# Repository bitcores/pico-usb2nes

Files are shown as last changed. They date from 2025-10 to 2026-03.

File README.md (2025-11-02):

# pico-usb2nes
RP2040 driven USB to controller interface for NES

This is based on the pico-usb2famikb project, using the same library for communicating with the NES/FC, but is focused on connecting to the controller port.

The only mode supported by default is the USB Keyboard Mouse Host mode (see [https://forums.nesdev.org/viewtopic.php?p=202489](https://forums.nesdev.org/viewtopic.php?p=202489) )

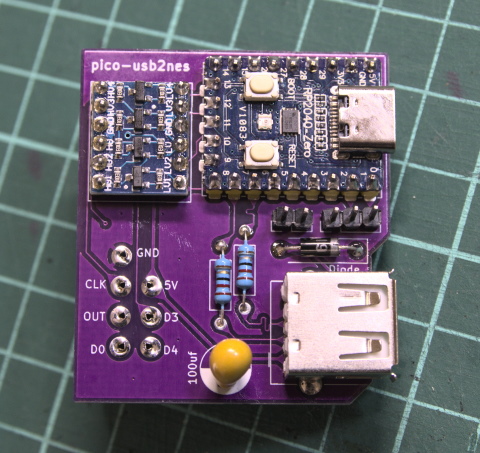
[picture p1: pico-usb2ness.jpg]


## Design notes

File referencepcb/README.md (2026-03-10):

# pico-usb2nes Reference PCB
This directory contains reference a PCB design for the pico-usb2nes. It has not been designed by a experienced engineer, but it DOES work.

If you have some experience designing circuits like this, I would very much welcome improved designs.

For the reference design you will need:
* 1x Waveshare compatible RP2040-Zero
* 1x diode (I am using a 1N5819, 1N5817 better)
* 1x USB A type female port
* 2x 22ohm resistors
* 1x 100uf 16v capacitor (input from console)
* 1x four-channel logic level converter
* 1x NES controller port (PCB mountable)
* 5x pin headers (optional for i2c)

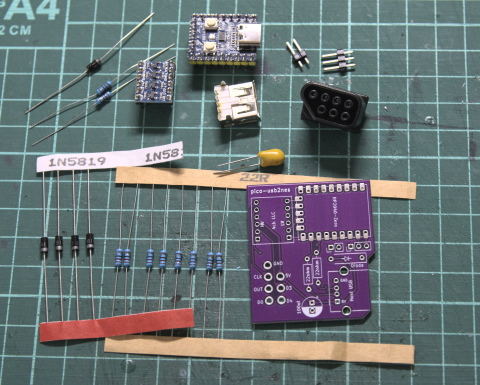
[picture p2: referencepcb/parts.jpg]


[This Youtube video](https://www.youtube.com/watch?v=ve_WcSxNZzQ) goes over the components and assembly.

These NES controller ports can be kinda hard to find, I will include a link to one source below (now unlisted, I am looking for other sources)

[https://aliexpress.com/item/1005009418780409.html](https://aliexpress.com/item/1005009418780409.html)

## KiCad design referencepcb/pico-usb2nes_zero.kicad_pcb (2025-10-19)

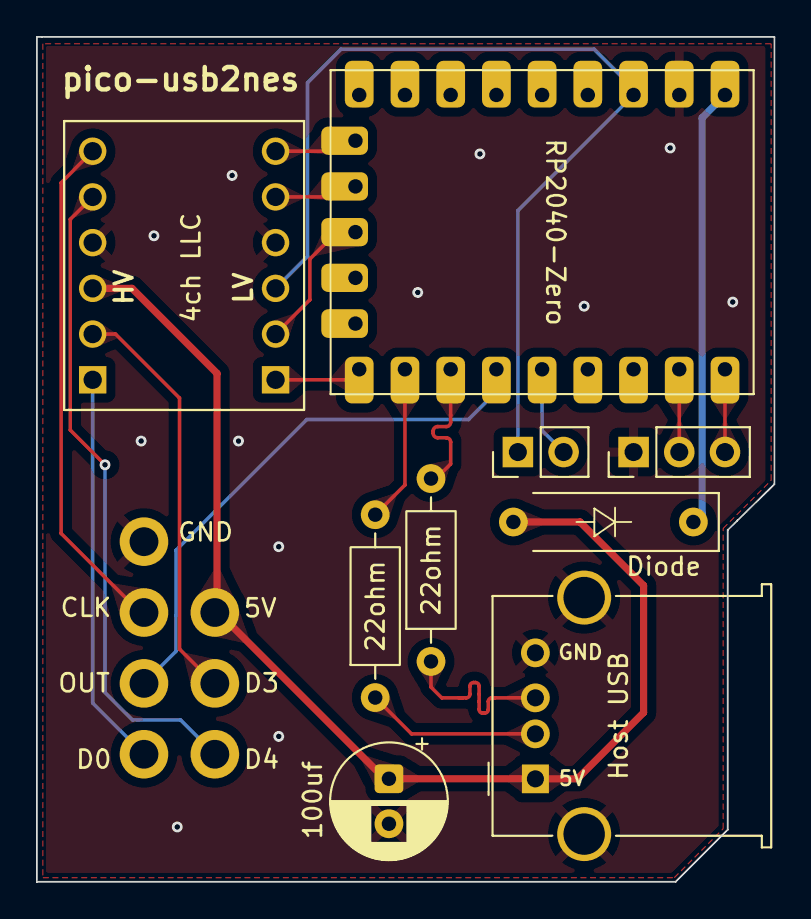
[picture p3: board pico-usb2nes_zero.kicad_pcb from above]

Board: 2 copper layers, 41.0 x 46.9 mm, 8 parts (0 on the bottom side), 9 nets.

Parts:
4ch LLC: CONV_BOB-12009
22ohm, 22ohm#2: R_Axial_DIN0207_L6.3mm_D2.5mm_P10.16mm_Horizontal
100uf: CP_Radial_D6.3mm_P2.50mm
Diode: D_MELF-RM10_Universal_Handsoldering
Host USB: USB_A_Molex_67643_Horizontal
NES Controller Port: NES controller port
i2cENABLE: PinHeader_1x02_P2.54mm_Vertical

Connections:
5V: 4ch LLC.HV, 100uf.1, Diode.2, Host USB.1, NES Controller Port.5V
GND: 4ch LLC.GND_1, 4ch LLC.GND_2, 100uf.2, Host USB.4, Host USB.5, NES Controller Port.G
nesd0: 4ch LLC.HV1, NES Controller Port.D0
nesd3: 4ch LLC.HV2, NES Controller Port.D3
nesd4: 4ch LLC.HV3, NES Controller Port.D4
nesoe2: 4ch LLC.HV4, NES Controller Port.C
pico3.3v: 4ch LLC.LV, i2cENABLE.1
usb_d+: 22ohm.1, Host USB.3
usb_d-: 22ohm#2.1, Host USB.2

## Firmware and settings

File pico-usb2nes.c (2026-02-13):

/* Copyright (C) 1883 Thomas Edison - All Rights Reserved
 * You may use, distribute and modify this code under the
 * terms of the GPLv2 license, which unfortunately won't be
 * written for another century.
 *
 * SPDX-License-Identifier: GPL-2.0-or-later
 */


#include <stdlib.h>
#include <stdio.h>
#include <string.h>
#include <hardware/i2c.h>
#include <pico/i2c_slave.h>

#include "pico/bootrom.h"
#include "pico/stdlib.h"
#include "pico/multicore.h"
#include "hardware/clocks.h"
#include "hardware/gpio.h"
#include "hardware/pio.h"
#include "hardware/irq.h"
#include "ws2812.pio.h"

#ifdef CYW43_WL_GPIO_LED_PIN
#include "pico/cyw43_arch.h"
#endif

#include "pio_usb.h"
#include "tusb.h"

#include "neskbdinter.h"
#include "usb2famikb.h"

// unnecessary now?
//#include "kblayout.c"

// $4016 "out" from AV Famicom/NES, only 1 pin
#define NES_OUT 5
// $4017 OE $4017 strobe read
#define NES_JOY2OE 13
// $4016 OE $4016 strobe read - unnecessary
#define NES_JOY1OE 3
// $4017 "data" lines, five consecutive pins
#define NES_DATA 8

// I2C communication pins
#define I2C_SDA_PIN 0
#define I2C_SCL_PIN 1

// direct input or i2chost select
#define i2cHOST_ENABLE 4

// backup led
#define BACKUP_LED 14


#define MAX_BUFFER 256  // lets use a circular buffer with 1 ubyte pointer
#define WORD_SIZE 4

// extra config for devices in direct input mode
#define MSERELATIVE 1
#define HORILHAND 1
#define HORILOWSPD 0
#define SENDREPEATS 1

// configuration for PIO USB
// DPDM configuration D+ = pin 6, D- = pin 7
// configure used SMs around currently used SMs
// use pio1, it has available SMs
// dp pin, usb tx pio, usb tx sm, usb tx dma
// usb rx pio, usb rx sm, usb eop sm
#define PIO_USB_CONFIG                                                          \
    {                                                                           \
        6, 1, 0, 0,                                                            \
            1, 1, 2,                                                            \
            NULL, PIO_USB_DEBUG_PIN_NONE,                                       \
            PIO_USB_DEBUG_PIN_NONE, false, PIO_USB_PINOUT_DPDM                  \
    }

#define MAX_REPORT 4
// Each HID instance can has multiple reports
static struct
{
  uint8_t report_count;
  tuh_hid_report_info_t report_info[MAX_REPORT];
}hid_info[CFG_TUH_HID];

static const uint8_t modkeys[] = { 
    KEY_LEFTCTRL, KEY_LEFTSHIFT, KEY_LEFTALT, KEY_LEFTMETA,
    KEY_RIGHTCTRL, KEY_RIGHTSHIFT, KEY_RIGHTALT, KEY_RIGHTMETA
};

// Just use a 6 byte memory array for storing the latest data for the mouse
static struct
{
    uint8_t mem[6];
    uint8_t mem_p;
    uint8_t mem_address;
    bool mem_address_written;
    bool garbage_message;
    bool skiplen;
} hostmsg;

static bool new_input_msg;
// FIFO buffer for keypresses for standard mode
static uint8_t keybuffer_i = 0;
static uint8_t keybuffer[MAX_BUFFER];
static uint8_t keybuffer_r = 0;
// mouse updates won't be buffered like the keyboard, if multiple updates come
// inbetween a frame, we want to put them together instead of stack them up
// oversizing the buffer type to mitigate overflow
static int16_t msebuffer[4];
// we want to store 
static int16_t mseinstbuf[4];
static volatile uint8_t joypadinst = 0;
// FIFO buffer for inputs in tasreplay mode
static uint8_t inpbuff_i = 0; // buffer input index
static uint8_t inpbuff[MAX_BUFFER];
static uint8_t inpbuff_r = 0; // buffer read index

static bool NESinlatch = false;

static uint8_t usb2kbmode;
static bool i2chostenable = false;
static uint8_t i2cmode = 0;

static bool instrobe = false;

static uint32_t kbword = 0;
static uint32_t mseword = 0;
static uint8_t nesjoypad = 0;

// gonna use arrow keys for dpad
// x for A, z for B, q for select, w for start
// if you are changing these keys, the order is important!
static const uint8_t neskeys[] = { KEY_X, KEY_Z, KEY_Q, KEY_W, 
                        KEY_UP, KEY_DOWN, KEY_LEFT, KEY_RIGHT };


// https://github.com/raspberrypi/pico-examples/blob/master/blink/blink.c
// Perform initialisation
int pico_led_init(void) {
#if defined(PICO_DEFAULT_LED_PIN)
    // A device like Pico that uses a GPIO for the LED will define PICO_DEFAULT_LED_PIN
    // so we can use normal GPIO functionality to turn the led on and off
    gpio_init(PICO_DEFAULT_LED_PIN);
    gpio_set_dir(PICO_DEFAULT_LED_PIN, GPIO_OUT);
    return PICO_OK;
#elif defined(CYW43_WL_GPIO_LED_PIN)
    // For Pico W devices we need to initialise the driver etc
    return cyw43_arch_init();
#elif defined(PICO_DEFAULT_WS2812_PIN)
    // for RP2040-Zero devices
    PIO pio = pio0;
    int sm = 1;
    uint offset = pio_add_program(pio, &ws2812_program);
    ws2812_program_init(pio, sm, offset, 16, 1120000, true);
    pio_sm_put_blocking(pio0, 1, 0); // ensure LED off
    sleep_ms(3);
    return PICO_OK;
#endif
}

// Turn the led on or off
void pico_set_led(bool led_on) {
#if defined(PICO_DEFAULT_LED_PIN)
    // Just set the GPIO on or off
    gpio_put(PICO_DEFAULT_LED_PIN, led_on);
#elif defined(CYW43_WL_GPIO_LED_PIN)
    // Ask the wifi "driver" to set the GPIO on or off
    cyw43_arch_gpio_put(CYW43_WL_GPIO_LED_PIN, led_on);
#elif defined(PICO_DEFAULT_WS2812_PIN)
    // for RP2040-zero devices
    if (led_on) {
        pio_sm_put_blocking(pio0, 1, 0x22222222); // dullwhite
    } else {
        pio_sm_put_blocking(pio0, 1, 0); // off
    }
#endif
}
// -----------------------------------------------------------

// handle key input into the buffer or matrices
static void keycode_handler(uint8_t ascii) {
    // keyboard mouse host mode
    keybuffer_i = (keybuffer_i + 1) % 256;
    keybuffer[keybuffer_i] = ascii;    
}

// I2C configuration
static const uint I2C_ADDRESS = 0x17;
static const uint I2C_BAUDRATE = 100000; // 100 kHz
// Our handler is called from the I2C ISR, so it must complete quickly. Blocking calls /
// printing to stdio may interfere with interrupt handling.
// =================
// the i2c host can send a variety of messages to different addresses
// this includes setting the mode of this device, requesting buffer state and
// delivering inputs for the buffer
// 0x00 - deliver inputs, 0x01 - buffer state, 0x10 - set mode
static void i2c_slave_handler(i2c_inst_t *i2c, i2c_slave_event_t event) {
    switch (event) {
    case I2C_SLAVE_RECEIVE: // master has written some data
        if (!hostmsg.mem_address_written) {
            // writes always start with the memory address
            hostmsg.mem_address = i2c_read_byte_raw(i2c);
            // the first value here is a len, ignore
            // address should be 0x00 for inputs, 0x10 for set mode
            hostmsg.garbage_message = !(hostmsg.mem_address == 0x00 || hostmsg.mem_address == 0x10);
            hostmsg.skiplen = (hostmsg.mem_address == 0x00);
            hostmsg.mem_address_written = true;
            hostmsg.mem_p = 0;
        } else {
            // if it is garbage we just read the values
            // but don't put them in memory
            // also the message len byte is skipped
            if (hostmsg.garbage_message || hostmsg.skiplen) {
                i2c_read_byte_raw(i2c);
                hostmsg.skiplen = false;
            }
            else { 
                // put the values into buffer
                if (hostmsg.mem_address == 0x00) {
                    if (i2cmode == 0x00) {
                        hostmsg.mem[hostmsg.mem_p] = i2c_read_byte_raw(i2c);
                        hostmsg.mem_p = (hostmsg.mem_p + 1) % 6;
                    } else if (i2cmode == 0x10) {
                        inpbuff_i = (inpbuff_i + 1) % 256;
                        inpbuff[inpbuff_i] = i2c_read_byte_raw(i2c);
                    }
                } else if (hostmsg.mem_address == 0x10) {
                    // this should be a single byte
                    i2cmode = i2c_read_byte_raw(i2c);
                } 
            }
        }
        break;
    case I2C_SLAVE_REQUEST: // master is requesting data
        i2c_write_byte_raw(i2c, i2cmode);
        uint8_t buffree = (inpbuff_r - inpbuff_i -1);
        i2c_write_byte_raw(i2c, buffree);
        break;
    case I2C_SLAVE_FINISH: // master has signalled Stop / Restart
        if (!hostmsg.garbage_message) {
            if (i2cmode == 0x00) {
                // parse the value from mem[1] if not 0x00
                if (hostmsg.mem[0] != 0x00) {
                    keycode_handler(hostmsg.mem[0]);
                }
                // only update mouse buffer if mouse is "present"
                if ((hostmsg.mem[1] & 32) == 32) {
                    // and the first byte with the current value
                    // this means if a button is pressed, it will stay "pressed"
                    // until the NES polls it (probably next frame)
                    msebuffer[0] |= hostmsg.mem[1];
                    // if true, we are in relative mode
                    if ((msebuffer[0] & 8) == 8 && new_input_msg) {
                        msebuffer[1] += (int8_t)hostmsg.mem[2];
                        msebuffer[2] += (int8_t)hostmsg.mem[3];
                    } else {
                        msebuffer[1] = (int8_t)hostmsg.mem[2];
                        msebuffer[2] = (int8_t)hostmsg.mem[3];   
                    }
                    // some wheel movements or middle button events could
                    // be missed. target for improvement later
                    msebuffer[3] |= hostmsg.mem[4];
                }
                new_input_msg = true;
            }
        }
        
        hostmsg.mem_address_written = false;
        
        break;
    default:
        break;
    }
}

// when mouse data is sent to the NES, update relevant buffer data
static void update_mouse_data() {
    // if there is new data from the host
    if (new_input_msg) {
        if (i2chostenable) {
            // actually update button values
            msebuffer[0] = hostmsg.mem[1];
            msebuffer[3] = hostmsg.mem[4];
        } else {
            msebuffer[0] = mseinstbuf[0];
            msebuffer[1] = mseinstbuf[1];
            msebuffer[2] = mseinstbuf[2];
            msebuffer[3] = mseinstbuf[3] & 0x87;
        }
        new_input_msg = false;
    }
}

// IRQ handler for OE lines to shift data
void pio_IRQ_handler() {

    if (pio_interrupt_get(pio0, 3)) {
        mseword = mseword << 1;
        kbword = kbword << 1;
        nesjoypad = nesjoypad >> 1;

        pio_interrupt_clear(pio0, 3);
    }
}


void nes_handler_thread() {
    pio_set_irq0_source_enabled(pio0, pis_interrupt3, true);
    irq_set_exclusive_handler(PIO0_IRQ_0, pio_IRQ_handler);
    
    irq_set_enabled(PIO0_IRQ_0, true);

    usb2famikb_init(NES_OUT, NES_JOY1OE, NES_JOY2OE, NES_DATA, usb2kbmode);

    while (true) {

        uint8_t nesread = (pio0->intr >> 8) & 0x0F;
        
        // read the strobe value, if was previously in strobe
        // exit strobe if no longer in strobe
        uint8_t strobe = nesread & 1;
        if (!strobe && instrobe) {
            instrobe = false;
        }

        // check for strobe signal and latch the buffers
        if (strobe && !instrobe) {  //  reset keyboard row/strobe mouse
            instrobe = true;
            // check if latched for buffer context
            NESinlatch = true;

            kbword = 0x00000000;
            mseword = 0x00000000;
            if (i2chostenable && i2cmode == 0x10) {
                // if the read pointer has not caught up to the input pointer
                // increment it. this should only happen when the tas replay
                // ends, or if you start the game before starting the replay
                if (inpbuff_r != inpbuff_i) {
                    inpbuff_r = (inpbuff_r + 1) % 256;
                }
                nesjoypad = inpbuff[inpbuff_r];
            } else {
                nesjoypad = joypadinst;
                // load the four oldest buffered values
                for (int i = 0; i < WORD_SIZE; i++) {
                    kbword = kbword << 8;
                    if (keybuffer_r != keybuffer_i) {
                        keybuffer_r = (keybuffer_r + 1) % 256;
                        kbword += keybuffer[keybuffer_r];
                    }
                    // mouse doesn't actually have a history
                    // just get the latest values
                    mseword = mseword << 8;
                    mseword += (uint8_t) msebuffer[i];
                }

                update_mouse_data();
            }

            NESinlatch = false;
        }

        uint32_t serialout = 0; // effectively D1 on the pico, doesn't go to nes
        // push next mouse bit in
        serialout |= (mseword & 0x80000000) >> 27;
        // push the next keyboard bit in
        serialout |= (kbword & 0x80000000) >> 28;
        // push the joypad bit, this could be connected to D0 or D1 on the port
        serialout |= (nesjoypad & 0x01);

        usb2famikb_putkb(~serialout);
 
    }

}

int main() {
    //  one rp2040-zero would not reliably set clock speed at default
    //  voltage. slight (0.05V) over-volt set to increase reliablity
    //  core temperatures will not be an issue (maybe slightly warm
    //  to the touch)
    //vreg_set_voltage(12);
    //sleep_ms(15);
    // need a clock speed that is a multiple of 12,000
    //set_sys_clock_khz(264000, true);
    // even stock clock speed of 120000 seems work for at least most
    // keyboard applications. higher clock will help ensure stability
    set_sys_clock_khz(168000, true);

    //  0: serialized mode - only mode supported
    usb2kbmode = 0;

    gpio_init(i2cHOST_ENABLE);
    gpio_set_dir(i2cHOST_ENABLE, GPIO_IN);
    gpio_pull_down(i2cHOST_ENABLE);
    
    i2chostenable = gpio_get(i2cHOST_ENABLE);

    // prepare buffers
    for (int i = 0; i < MAX_BUFFER; i++) {
        keybuffer[i] = 0x00;
    }
    for (int i = 1; i < 4; i++) {
        msebuffer[i] = 0x00;
        mseinstbuf[i] = 0x00;
    }
    // set only the device id in the buffer so if the NES
    // strobes for update before data received it will know
    // the interface is present
    msebuffer[0] = mseinstbuf[0] = 0x06;
    joypadinst = 0x00;

    multicore_reset_core1();
    //  run the NES handler on seperate core
    multicore_launch_core1(nes_handler_thread);

    // init the LED
    pico_led_init();
    if (i2chostenable) {
        gpio_init(I2C_SDA_PIN);
        gpio_set_function(I2C_SDA_PIN, GPIO_FUNC_I2C);
        gpio_pull_up(I2C_SDA_PIN);

        gpio_init(I2C_SCL_PIN);
        gpio_set_function(I2C_SCL_PIN, GPIO_FUNC_I2C);
        gpio_pull_up(I2C_SCL_PIN);

        i2c_init(i2c0, I2C_BAUDRATE);
        // configure I2C0 for slave mode
        i2c_slave_init(i2c0, I2C_ADDRESS, &i2c_slave_handler);

        // everything configured, turn on the LED
        pico_set_led(true);
        // loop forever now
        while (true) {
            tight_loop_contents();
        }
        
    }
    else {
        mseinstbuf[0] |= MSERELATIVE << 3;
        sleep_ms(10);

        // Use tuh_configure() to pass pio configuration to the host stack
        // Note: tuh_configure() must be called before
        pio_usb_configuration_t pio_cfg = PIO_USB_CONFIG;
        tuh_configure(1, TUH_CFGID_RPI_PIO_USB_CONFIGURATION, &pio_cfg);

        // To run USB SOF interrupt in core0, init host stack for pio_usb (roothub
        // port1) on core0
        tuh_init(1);
        // everything configured, turn on the LED
        pico_set_led(true);

        while (true) {
            tuh_task(); // tinyusb host task
        }
    }

}

//--------------------------------------------------------------------+
// Host HID
//--------------------------------------------------------------------+

// Invoked when device with hid interface is mounted
// Report descriptor is also available for use. tuh_hid_parse_report_descriptor()
// can be used to parse common/simple enough descriptor.
// Note: if report descriptor length > CFG_TUH_ENUMERATION_BUFSIZE, it will be skipped
// therefore report_desc = NULL, desc_len = 0
void tuh_hid_mount_cb(uint8_t dev_addr, uint8_t instance, uint8_t const* desc_report, uint16_t desc_len)
{
    (void)desc_report;
    (void)desc_len;

    // Interface protocol (hid_interface_protocol_enum_t)
    uint8_t const itf_protocol = tuh_hid_interface_protocol(dev_addr, instance);

    // Receive report from boot keyboard & mouse only
    // tuh_hid_report_received_cb() will be invoked when report is available
    if (itf_protocol == HID_ITF_PROTOCOL_KEYBOARD || itf_protocol == HID_ITF_PROTOCOL_MOUSE) {
        switch (itf_protocol) {
            case (HID_ITF_PROTOCOL_KEYBOARD):
                mseinstbuf[0] |= 0x10;
                break;
            case (HID_ITF_PROTOCOL_MOUSE):
                mseinstbuf[0] |= 0x20;
                break;
        }
        new_input_msg = true;
    } else {
        // for when device is not a boot type (gamepads for example)
        hid_info[instance].report_count = tuh_hid_parse_report_descriptor(hid_info[instance].report_info, MAX_REPORT, desc_report, desc_len);
    }
    //  set up report receiving
    tuh_hid_receive_report(dev_addr, instance);
}

// Invoked when device with hid interface is un-mounted
void tuh_hid_umount_cb(uint8_t dev_addr, uint8_t instance)
{
    uint8_t const itf_protocol = tuh_hid_interface_protocol(dev_addr, instance);
    
    switch (itf_protocol) {
        case (HID_ITF_PROTOCOL_KEYBOARD):
            mseinstbuf[0] &= 0xEF;
            break;
        case (HID_ITF_PROTOCOL_MOUSE):
            mseinstbuf[0] &= 0xDF;
            break;
        default:
            break;
    }
    new_input_msg = true;
}

// look up new key in previous keys
static inline bool find_key_in_report(hid_keyboard_report_t const *report, uint8_t keycode)
{
    for(uint8_t i=0; i<6; i++) {
        if (report->keycode[i] == keycode)  return true;
    }

    return false;
}

// check if a keycode is missing from prev report
static inline void find_releases_in_report(hid_keyboard_report_t const *prev_report, hid_keyboard_report_t const *report)
{
    for(uint8_t i=0; i<6; i++)
    {
        if (prev_report->keycode[i] == 0x00) { break; }
        if (prev_report->keycode[i] != report->keycode[i]) {
            keycode_handler(prev_report->keycode[i] + 0x80);
            break;
        }
    }
}

// check if modifier keys have changed
static inline void update_modifiers(hid_keyboard_report_t const *prev_report, hid_keyboard_report_t const *report)
{
    uint8_t c = 1;
    for(uint8_t i=0; i<8; i++)
    {
        if ((prev_report->modifier & c) != (report->modifier & c)){
            if ((report->modifier & c) == 0){ // modifier released
                keycode_handler(modkeys[i] + 0x80);
            } else {
                keycode_handler(modkeys[i]);
            }
        }
        c <<= 1;
    }
}

// process the kbd report and send to keycode handler
static void process_kbd_report(hid_keyboard_report_t const *report)
{
    static hid_keyboard_report_t prev_report = { 0, 0, {0} }; // previous report to check key released
    uint8_t newjoypad = 0x00;
    // keycode positions change when released, so need to check all
    find_releases_in_report(&prev_report, report);
    // check if modifier keys have changed
    update_modifiers(&prev_report, report);

    for(uint8_t i=0; i<6; i++)
    {
        uint8_t keycode = report->keycode[i];
        if ( keycode )
        {
            if (find_key_in_report(&prev_report, keycode)) {
                // ignore for now would like a repeat thing
            } else {
                keycode_handler(keycode);
            }
            for (uint8_t j = 0; j < 8; j++) {
                if (keycode == neskeys[j]) {
                    newjoypad |= (1 << j);
                    break;
                }
            }
        }
    }
    joypadinst = newjoypad;
    prev_report = *report;
}

// process the mouse report and insert into buffers
static void process_mouse_report(hid_mouse_report_t const *report)
{
    uint8_t temp = mseinstbuf[0] & 0x3F;
    temp |= (report->buttons & MOUSE_BUTTON_LEFT) << 7;
    temp |= (report->buttons & MOUSE_BUTTON_RIGHT) << 5;
    mseinstbuf[0] = temp;
    msebuffer[0] |= mseinstbuf[0];

    temp = 0x00;
    temp |= (report->buttons & MOUSE_BUTTON_MIDDLE) << 5;
    temp |= (report->wheel & 0x0F) << 3;
    temp |= HORILHAND << 1;
    temp |= HORILOWSPD;
    mseinstbuf[3] = temp;
    msebuffer[3] |= mseinstbuf[3];

    if (MSERELATIVE) {
        if (new_input_msg) {
            msebuffer[1] += report->x;
            msebuffer[2] += report->y;
            mseinstbuf[1] = report->x;
            mseinstbuf[2] = report->y;
        } else {
            msebuffer[1] = mseinstbuf[1] = report->x;
            msebuffer[2] = mseinstbuf[2] = report->y;
        }
    } else {
        mseinstbuf[1] += report->x;
        if (mseinstbuf[1] < 0) { mseinstbuf[1] = 0; }
        if (mseinstbuf[1] > 255) { mseinstbuf[1] = 255; }

        mseinstbuf[2] += report->y;
        if (mseinstbuf[2] < 0) { mseinstbuf[2] = 0; }
        if (mseinstbuf[2] > 255) { mseinstbuf[2] = 255; }
        
        msebuffer[1] = mseinstbuf[1];
        msebuffer[2] = mseinstbuf[2];
    }

    new_input_msg = true;

}
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

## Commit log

2025-10-19 add pcb and gerbers
    [pico-usb2nes_zero.kicad_pcb]
2026-02-13 update i2c keyboard mouse handling
    fixed up how keyboard/mouse messages are handled via i2c
    [pico-usb2nes.c]
